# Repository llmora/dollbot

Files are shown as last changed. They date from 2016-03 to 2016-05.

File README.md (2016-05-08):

# dollbot
Water surface autonomous vehicle with holonomic propulsion

More information on http://splashbots.blogspot.com/

Mechanical design
-----------------
The "mechanical" directory includes the CAD design files for the pieces used in dollbot (as well as the STL renderings, ready to 3D print).

The designs are parametric, so you can adjust and play with different measurements - just use OpenSCAD to visualise the results and export to STL. If you plan to work with the SCAD files you will need to install the ["nutsnbolts"](https://github.com/JohK/nutsnbolts)
OpenSCAD library. You can do that easily using git as the dollbot project already include the appropriate references to pull any supporting libraries:
```
$ git submodule init
$ git submodule update
```

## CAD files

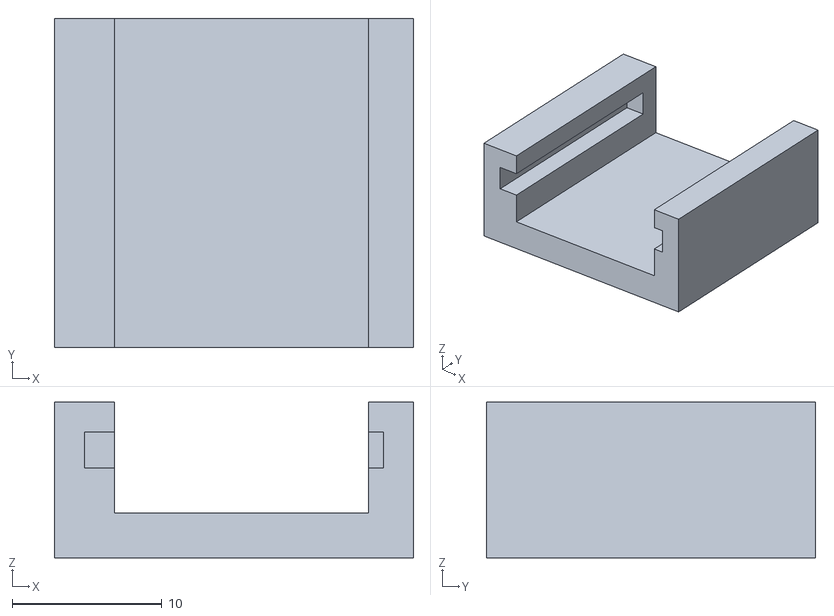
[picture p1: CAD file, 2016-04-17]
mechanical/compass_holder.stl
24.0 x 22.0 x 10.4

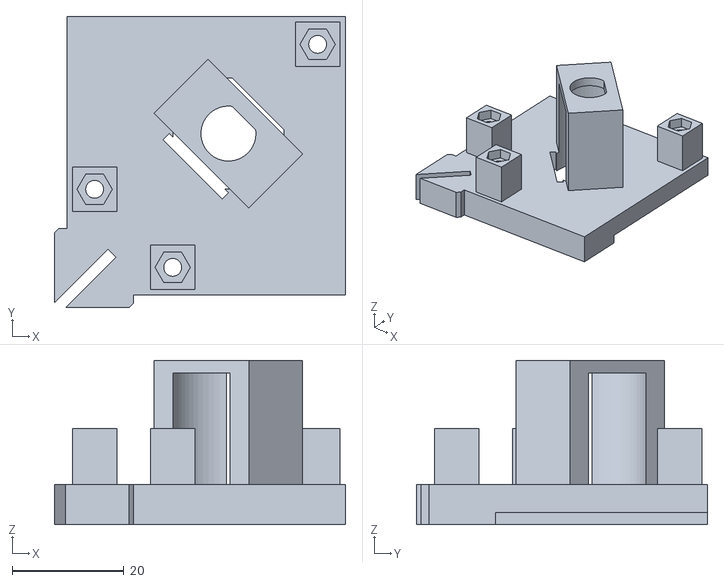
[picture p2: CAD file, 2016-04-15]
mechanical/dollbot_thruster_internal.stl
52.2 x 52.2 x 29.4

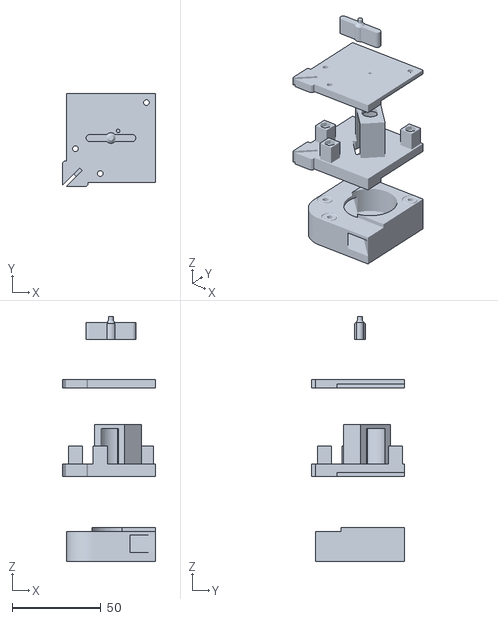
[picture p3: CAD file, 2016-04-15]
mechanical/dollbot_thruster_all.stl
52.2 x 52.2 x 138.0

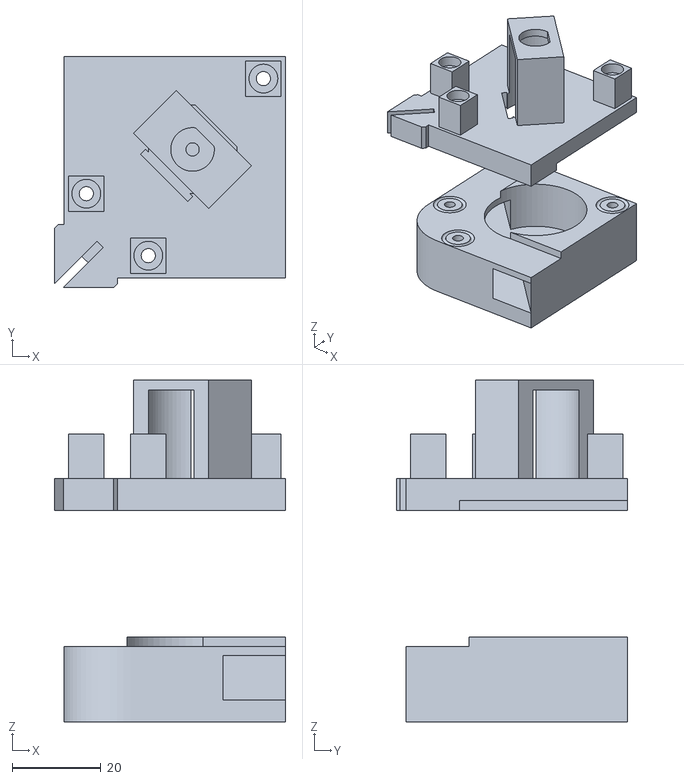
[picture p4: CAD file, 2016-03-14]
mechanical/dollbot_thruster.stl
52.2 x 52.2 x 77.2

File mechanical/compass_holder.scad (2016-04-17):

/*
  HMC5883L Compass holder for Dollbot (http://splashbots.blogspot.com/)

  Small plastic piece to slide-in and hold the 3-axis compass in place in the dollbot hull.
  
  Recommended 20% in-fill with no supports

*/

compass_length = 20;
compass_width = 18;
compass_height= 2.4;
compass_bottom_clearance = 3;
compass_top_clearance = 2;

base_height = 3;

holder_wall_thickness = 2;
holder_length = compass_length + holder_wall_thickness + holder_wall_thickness;
holder_width = compass_width + holder_wall_thickness + holder_wall_thickness;
holder_height = compass_height + base_height + compass_bottom_clearance + compass_top_clearance;

difference() {
  cube([holder_length, holder_width, holder_height]);

  translate([2 * holder_wall_thickness, 0, base_height]) {
    cube([compass_length - 2 - 1, compass_width + holder_wall_thickness + holder_wall_thickness, compass_height + compass_bottom_clearance + compass_top_clearance]);
  }
  
  translate([holder_wall_thickness, 0, base_height + compass_bottom_clearance]) {
      cube([compass_length, compass_width + holder_wall_thickness, compass_height]);
  }
}

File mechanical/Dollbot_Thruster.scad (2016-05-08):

/*
  Holonomic thruster for Dollbot (http://splashbots.blogspot.com/)

  The drawing includes the internal and external components for the thruster as well as the turbines and a stencil to help drill the appropriate holes on the boat hull.

  You should print 4 of each of the components (except for the stencil, of which you need only one). Recommendations are:

  * 4 x External thruster: 20% fill, Supports
  * 4 x Internal thruster: 20% fill, Supports
  * 4 x Turbines: 20% fill, No Supports
  * 1 x Stencil: 20% fill, No Supports

*/

include <nutsnbolts/cyl_head_bolt.scad>;

$fn = 60;

piece_separation = 50;

base_side = 50;
base_height = 5;

pillar_side = 8;
pillar_height = 10; // Should be 30
pillar_base_offset = 1;
pillar_base_offset_side = 3;

pillar_screw_offset = 10;
pillar_screw_name="M3x30";
pillar_screw_details = _get_screw(pillar_screw_name);
pillar_screw_fam = _get_screw_fam(pillar_screw_name);

latch_depth = 2.20;
latch_side = 12 + latch_depth;
latch_fin_length = latch_side;
latch_fin_width = 2;

motor_width = 15.05;
motor_length = 20;
motor_height = 25;

motor_offset = 4;

motor_top_height = 4.5;
motor_top_overhang = 1.55;

motor_holder_radius = 9.85 / 2;
motor_holder_cutoff = 1;
motor_shaft_radius = 1;
motor_shaft_length = 8.4;
motor_shaft_cover_radius = motor_shaft_radius * 3;

thruster_jet_side = 10;
thruster_top_height = 2;
thruster_bottom_height = 5;
thruster_height = thruster_top_height + thruster_jet_side + thruster_bottom_height;
thruster_paddle_radius = 15;
thruster_hull_radius = 15;
thruster_pin_depth = 2;
thruster_pin_radius = 1.5;

rubber_rim_width = 0.6;
drilling_stencil_height = base_height;

thruster_pin_depth = 2;
thruster_pin_radius = 1.5;

turbine_radius = 3;
turbine_height = 13;
turbine_top_radius = thruster_pin_radius * 0.9;
turbine_wings = 2;
turbine_wing_height = turbine_height - 3.50;
turbine_wing_length = 14;
turbine_wing_width = 4;
turbine_bottom_offset = 0;

module pillar(x,y) {
  translate([x-(pillar_side/2), y-(pillar_side/2), base_height]) {
    cube([pillar_side, pillar_side, pillar_height]);
  }
}

module pillar_screw_holes(x, y) {
  ds = _get_screw(pillar_screw_name);
  df = _get_screw_fam(pillar_screw_name);

  union() {
    //translate([x, y, 15.0001 + df[_NB_F_HEAD_HEIGHT]]) {
    translate([x, y, pillar_height + base_height/2 + df[_NB_F_HEAD_HEIGHT] - 0.4999]) {
      nut(df[_NB_F_DESC]);
      hole_through(df[_NB_F_DESC], l=ds[_NB_S_LENGTH] + 100);// h=df[_NB_F_HEAD_HEIGHT]);
      translate([0,0,-piece_separation - thruster_height + df[_NB_F_HEAD_HEIGHT] - 1.1]) {
        rotate(a=180, v=[1,0,0]) {
        hole_through(df[_NB_F_DESC], l=ds[_NB_S_LENGTH] + 100);//, h=df[_NB_F_HEAD_HEIGHT]);
        }
      }
    };
  }
}

// Inside part of the thruster

// Base
module thruster(show_motor_gap) {
  difference() {
    union() {
      translate([0,0,base_height/2]) {
        intersection() {
          union() {
            cube([base_side, base_side, base_height], center=true);

            // Sides

            translate([-base_side/2, -base_side/2, -latch_depth - base_height/2]) {
              cube([latch_side - latch_depth, base_side, latch_depth]);
              translate([0, latch_side-latch_depth, 0]) {
                rotate(a=270, v=[0,0,1]) {
                  cube([latch_side - latch_depth, base_side, latch_depth]);
                }
              }
            }
          }
        }
      };

      // Improve the connection with the bottom of the Dollbot hull

      translate([-base_side/2 - latch_depth, -base_side/2 - latch_depth, -latch_depth]) {

        // Corner

        intersection() {
          translate([latch_side/2,latch_side/2, 0]) {
            cylinder(r=latch_side/2 + (latch_side/6), h = base_height + latch_depth);
          }

          cube([latch_side, latch_side, base_height + latch_depth]);
        };
      }



      // Pillars for screws

      pillar(base_side/2 - pillar_side/2 - pillar_base_offset, base_side/2 - pillar_side/2 - pillar_base_offset);
      pillar(-base_side/2 + pillar_base_offset + pillar_side/2, -pillar_base_offset_side * 2);
      pillar(-pillar_base_offset_side * 2, -base_side/2 + pillar_base_offset + pillar_side/2);

      // DC130 motor holder
      translate([motor_offset, motor_offset, 0]) {
        rotate(a=135, v=[0, 0, 1]) {
          difference() {
            translate([0, 0, (motor_height+base_height)/2]) {
              cube([motor_length*1.2, motor_width/1.10, motor_height + motor_top_height - base_height], center=true);
            };

          // Top of the motor holder indentation to keep motor from moving around

            translate([0,0,motor_height-motor_top_height/2]) {
              difference() {
                cylinder(r=motor_holder_radius, h=motor_top_height);

                translate([-motor_holder_radius, -motor_holder_radius, 0]) {
                  cube([motor_holder_radius*2, motor_holder_cutoff, motor_top_height]);
                }
              };
            }
          };
        }
      }

      translate([base_side/2,-base_side/2,-piece_separation]) {
        rotate(a=90, v=[0,0,1]) {
          // external_thruster();
        }
      }
  }

    // Screw holes

    pillar_screw_holes(base_side/2 - pillar_side/2 - pillar_base_offset, base_side/2 - pillar_side/2 - pillar_base_offset);
    pillar_screw_holes(-base_side/2 + pillar_base_offset + pillar_side/2, -pillar_base_offset_side * 2);
    pillar_screw_holes(-pillar_base_offset_side * 2, -base_side/2 + pillar_base_offset + pillar_side/2);

    translate([-base_side/2 - latch_depth, -base_side/2 - latch_depth, 0]) {
      translate([latch_fin_width/2, -latch_fin_width/2, -latch_depth - 1]) {
        rotate(a=45, v = [0,0,1]) {
          cube([latch_fin_length, latch_fin_width, base_height + latch_depth + 2]);
        }
      }
    }

    // Motor holder block
    if(show_motor_gap) {
      translate([motor_offset, motor_offset, 0]) {

        rotate(a=135, v=[0, 0, 1]) {

          translate([-motor_length/2, -motor_width/2, -latch_depth]) {

            union() {
              intersection() {
                cube([motor_length, motor_width, motor_height+latch_depth]);
                translate([motor_length/2, motor_width/2,0]) {
                  cylinder(r=motor_length/2, h=motor_height+latch_depth);
                }
              };

              translate([(motor_length - motor_width)/2, motor_width, 0]) {
                cube([motor_width, motor_top_overhang, motor_height+latch_depth]);
              }
            }
          };
        }
      }

    } else {
      // Hole for drilling template instead of the motor holder block
      translate([motor_offset, motor_offset, -base_height/2]) {
        // cylinder(r = motor_shaft_cover_radius, h = 100);
        cylinder(r = motor_shaft_radius, h = 100);
      }

    }

  }

}


// Module: External thruster
module external_thruster() {

  difference() {

    union() {
      cube([base_side, base_side, thruster_height]);

      translate([latch_side,0,thruster_height]) {
        difference() {
          cube([base_side - latch_side, base_side - latch_side, latch_depth]);
          translate([0,base_side - (2*latch_side), 0]) {
            cube([latch_side, latch_side, latch_depth]);
          }
        }
      }
    }

    rubber_rim(pillar_base_offset + pillar_side/2, base_side/2 + pillar_side/2 + pillar_base_offset * 2, thruster_height);
    rubber_rim(base_side/2 - pillar_base_offset * 2 - pillar_side/2 , base_side - pillar_side/2 - pillar_base_offset, thruster_height);
    rubber_rim(base_side - pillar_side/2 - pillar_base_offset, pillar_side/2 + pillar_base_offset, thruster_height + latch_depth);

    translate([thruster_hull_radius-0.0001, base_side - thruster_hull_radius, 0]) {
      rotate(a=90, v=[0,0,1]) {
        difference() {
          cube([thruster_hull_radius, thruster_hull_radius, thruster_height]);
          cylinder(r=thruster_hull_radius, h=thruster_height);
        }
      }
    }

    translate([0,0,thruster_bottom_height]) {
      rotate(a=45, v=[0,0,1]) {
        cube([sqrt(2 * pow(base_side, 2)), thruster_jet_side, thruster_jet_side]);
      }
    }

    translate([base_side/2 + motor_offset, base_side/2 - motor_offset, thruster_bottom_height]) {
      cylinder(r=thruster_paddle_radius, h = thruster_top_height + thruster_jet_side + latch_depth);
      translate([0,0,-thruster_pin_depth]) {
        cylinder(r=thruster_pin_radius, h=thruster_pin_depth);
      }
    }
  }
}

module rubber_rim(x, y, z) {
  df = _get_screw_fam(pillar_screw_name);

  translate([x, y, z]) {
    rotate_extrude(convexity = 10)
    translate([df[_NB_F_OUTER_DIA] + rubber_rim_width * 2, 0, 0])
    circle(r = rubber_rim_width);
  }
}

module drilling_stencil() {
  intersection() {
    thruster(false);
    translate([-base_side, -base_side, -base_height/2]) {
      cube([base_side * 2, base_side * 2, drilling_stencil_height]);
    }
  }
}
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

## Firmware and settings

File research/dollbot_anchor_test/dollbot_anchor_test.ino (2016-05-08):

/*
  dollbot_anchor_test: Anchor dollbot in a specific heading

  Control the dollbot via the remote control interface, once control is released the dollbot will stay anchored in the same orientation using its built-in
  magnetic compass.
  
  http://splashbots.blogspot.com/
  
  Based on Sparkfun's "RC Hobby Controllers and Arduino": https://www.sparkfun.com/tutorials/348
  Requires Adafruit MotorShield v2: http://www.adafruit.com/products/1438
  Requires Adafruit HMC5883 and Adafruit sensor library https://learn.adafruit.com/adafruit-hmc5883l-breakout-triple-axis-magnetometer-compass-sensor/

*/

#include <Wire.h>
#include <Adafruit_MotorShield.h>
#include <Adafruit_Sensor.h>
#include <Adafruit_HMC5883_U.h>

// #define DEBUG // Define if you are debugging the project - note that a huge amount of serial debugging plus a 500ms delay is added to each loop to be able to follow serial output, so debugging heavily interferes with any real-time operation.
// #define DEBUG_DRYDOCK // Define together with DEBUG if you are doing workbench testing with no need to have actual motor movement. Generally you do not want the water-designed motors to be spinning out of water for a long period of time.

#define PIN_CH1 7
#define PIN_CH2 6
#define PIN_CH3 5
#define PIN_CH4 4

#define MOTOR_FL 1
#define MOTOR_FR 2
#define MOTOR_BL 3
#define MOTOR_BR 4

// These two values need to be adjusted depending on your RC receiver. Typical values are 1000-2000, see the Sparkfun article referenced above.
#define PWM_LOW 1000
#define PWM_HIGH 1900

#define RC_THRESHOLD 10 // Minimum value of an RC input to move to manual control
#define MOTOR_THRESHOLD 5 // Minimum value of a motor input to spin, smaller than this is considered noise

#define MOTOR_MAX 255

void vehicleMove(int valX, int valY, int valRotate);
void vehicleStop();
void HolonomicMove(int xComponent, int yComponent, int rotationComponent);
void HolonomicSpin(int mm[4]);
void HolonomicSimplify(int mm[4]);
int rotationalDeviation(int initial, int target);

// Holonomic matrix - connect all motors to the motor shield in the same position. If movement is not as expected change the connections (do not change the table below).

int verticalMove[4] =   {-1, -1, -1, -1};
int horizontalMove[4] = {-1, +1, +1, -1};
int rotationMove[4] =   {-1, +1, -1, +1};

// Control variables
int manualControl;
float anchorHeading = 0;

// Create the motor shield object with the default I2C address
Adafruit_MotorShield AFMS = Adafruit_MotorShield(); 
Adafruit_DCMotor *motor[4] = {AFMS.getMotor(MOTOR_FL), AFMS.getMotor(MOTOR_FR), AFMS.getMotor(MOTOR_BL), AFMS.getMotor(MOTOR_BR)};

// Initialise the compass
Adafruit_HMC5883_Unified compass = Adafruit_HMC5883_Unified(8431);

void setup() {
  // Initialize serial communications
  Serial.begin(9600);
  Serial.println("");
  Serial.print("DOLLBOT v1.0 (");

#ifdef DEBUG_DRYDOCK
  Serial.print("DRYDOCK ");
#endif

#ifdef DEBUG
  Serial.print("DEBUG");
#else
  Serial.print("PRODUCTION");
#endif

  Serial.print(") initialising");

  // Seep for 3 seconds
  for(int i=0; i < 3; i++) {
    delay(1000);
    Serial.print(".");
  }
  
  Serial.println("");

  AFMS.begin();  // create with the default frequency 1.6KHz

  /* Initialise the compass */
  if(!compass.begin()) {
    Serial.println("HMC5883 compass not detected, stopping.");
    while(1);
  }
  
  Serial.println("HMC5883 compass initialised");

  // Initialize the ports where we will read receiver input
  pinMode(PIN_CH1, INPUT);
  pinMode(PIN_CH2, INPUT);
  pinMode(PIN_CH3, INPUT);
  pinMode(PIN_CH4, INPUT);

  // Automated control initialisation
  manualControl = 1; 

  Serial.println("DOLLBOT Initialisation completed");
}

void dumpContent(int mm[4]) {
  Serial.print("MOTOR: Input array: ");
  for(int i=0; i < 4; i++) {
    Serial.print(mm[i]);
    Serial.print(",");
  }
  Serial.print(". ");
}

void HolonomicSpin(int mm[4]) {
  HolonomicSimplify(mm);

#ifdef DEBUG
  Serial.print("MOTOR: Setting speeds: ");
#endif

  for(int i = 0; i < 4; i++) {
    
    // Expand range to motor limits
    mm[i] = map(mm[i], -100, 100, -1 * MOTOR_MAX, MOTOR_MAX);
    
    if(abs(mm[i]) > (MOTOR_THRESHOLD * MOTOR_MAX) / 100) {

#ifndef DEBUG_DRYDOCK
      motor[i]->setSpeed(abs(mm[i]));
      motor[i]->run(mm[i] > 0? FORWARD : BACKWARD);
#endif

#ifdef DEBUG
      Serial.print(mm[i]);
#endif
    } else {

#ifndef DEBUG_DRYDOCK
      motor[i]->setSpeed(0);
      motor[i]->run(RELEASE);
#endif

#ifdef DEBUG
      Serial.print("STP");
#endif
    }

#ifdef DEBUG
    if(i < 3) {
      Serial.print(",");
    } else {
      Serial.println("");
    }
#endif
  }
}

void HolonomicSimplify(int mm[4]) {
  int max = 0;

  for(int i = 0; i < 4; i++) {
    int currentValue = abs(mm[i]);
    
    if(currentValue > max) {
      max = currentValue;
    }
  }
  
  // Scale the values so that we stay within the -100 .. 100 range

  if(max > 100) {
    for(int i = 0; i < 4; i++) {
      mm[i] = map(mm[i], -1 * max, max, -100, 100);
    }
  }

}

void HolonomicMove(int xComponent, int yComponent, int rotationComponent) {
  int mm[4] = {0, 0, 0, 0};
  
  if(xComponent) {
    for(int i = 0; i < 4; i++) {
      mm[i] += horizontalMove[i] * xComponent;
    }
  }

  if(yComponent) {
    for(int i = 0; i < 4; i++) {
      mm[i] += verticalMove[i] * yComponent;
    }
  }
  
  if(rotationComponent) {
    for(int i = 0; i < 4; i++) {
      mm[i] += rotationMove[i] * rotationComponent;
    }
  }
  
  HolonomicSpin(mm);
}


/*
  Helper function to move the vehicle 
 
*/

void vehicleMove(int valX, int valY, int valRotate) {
  HolonomicMove(valX, valY, valRotate);
}

void vehicleStop() {
  vehicleMove(0, 0, 0);
}

// From: http://gmc.yoyogames.com/index.php?showtopic=532420

int rotationalDeviation(int initial, int target) {
  return (((target - initial) % 360) + 360 + 180) % 360 - 180;
}

void loop() {
  sensors_event_t compassEvent;
  float heading;

  // Read three of the channels of the RC receiver, we only use three - but you can add a fourth one if needed

  int channelHorizontal = pulseIn(PIN_CH4, HIGH, 25000); // X axis movement
  int channelVertical = pulseIn(PIN_CH2, HIGH, 25000); // Y axis movement
  int channelRotate = pulseIn(PIN_CH1, HIGH, 25000); // Rotation
    
  int directionHorizontal = map(channelHorizontal, PWM_LOW, PWM_HIGH, -100, 100);
  int directionVertical = map(channelVertical, PWM_LOW, PWM_HIGH, -100, 100);
  int angleRotate = map(channelRotate, PWM_LOW, PWM_HIGH, -100, 100);
  
  // If we are receiving control commands from the RC controller bypass autonomous mode

  if((channelHorizontal || channelVertical || channelRotate) && // If we are receiving no pulses it means we are not connected to RC, so ignore manual control
     (abs(directionHorizontal) > RC_THRESHOLD || abs(directionVertical) > RC_THRESHOLD || abs(angleRotate) > RC_THRESHOLD)) { // RC signals are not perfect, we allow for a 10% threshold before switching to it
    
    manualControl = 1;
    
    // Map all readings to a -100 .. +100 range so it is easy to deal with

#ifdef DEBUG    
    Serial.print("MANUAL: RC control ");

    Serial.print("H: ");
    Serial.print(directionHorizontal);

    Serial.print(" V: ");
    Serial.print(directionVertical);

    Serial.print(" R: ");
    Serial.println(angleRotate);
#endif

    vehicleMove(directionHorizontal, directionVertical, angleRotate);
    
  } else {
    // Autonomous control
    compass.getEvent(&compassEvent);
    heading = int(atan2(compassEvent.magnetic.y, compassEvent.magnetic.x) * 180/M_PI + 360) % 360; // Convert radians to degrees
    
    if(manualControl == 1) {
      manualControl = 0;
      // We just came here from being controlled by the RC. Stop all engines and get our anchor heading

      vehicleStop();

      anchorHeading = heading;
#ifdef DEBUG
      Serial.print("AUTONOMOUS: Set new anchor heading: ");
      Serial.println(anchorHeading);
#endif

    } else {
      // Get our current heading and correct it so we remain close to anchor
      int deviation = rotationalDeviation(anchorHeading, heading);

      if(abs(deviation) > 1) {
#ifdef DEBUG
        Serial.print("AUTONOMOUS: Correcting heading by ");
        Serial.println(deviation);
#endif
        vehicleMove(0, 0, deviation);
      } else {
        vehicleStop();

#ifdef DEBUG
        Serial.print("AUTONOMOUS: Not moving, only a small deviation: ");
        Serial.println(deviation);
#endif
      }
      
    }
  }

#ifdef DEBUG  
 delay(1000);
#endif
}

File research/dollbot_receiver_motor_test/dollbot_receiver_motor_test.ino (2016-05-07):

/*
  dollbot_receiver_motor_test: Control a motor using the 4-CH RC receiver.
  
  This sketch polls three of the channels of the RC receiver and spins a motor when one of the channels is working. Designed to test the
  Adafruit motor shield with the RC motor and the motor casing as part of leak testing.
  
  http://splashbots.blogspot.com/
  
  Based on Sparkfun's "RC Hobby Controllers and Arduino": https://www.sparkfun.com/tutorials/348
*/

#include <Wire.h>
#include <Adafruit_MotorShield.h>

#define DEBUG

#define PIN_CH1 7
#define PIN_CH2 6
#define PIN_CH3 5
#define PIN_CH4 4

#define TEST_MOTOR 4

#define PWM_LOW 1000
#define PWM_HIGH 2000
#define RC_THRESHOLD 10

#define AXIS_X 0
#define AXIS_Y 1

#define MOTOR_MAX 255

// Create the motor shield object with the default I2C address
Adafruit_MotorShield AFMS = Adafruit_MotorShield(); 

// Select which 'port' M1, M2, M3 or M4. In this case, M1
Adafruit_DCMotor *testMotor= AFMS.getMotor(TEST_MOTOR);

void setup() {
  // Initialize serial communications
  Serial.begin(9600);
  Serial.println("Initializing input...");
  
  AFMS.begin();  // create with the default frequency 1.6KHz

  // Initialize the ports where we will read receiver input
  pinMode(PIN_CH1, INPUT);
  pinMode(PIN_CH2, INPUT);
  pinMode(PIN_CH3, INPUT);
  pinMode(PIN_CH4, INPUT);

}

void HolonomicMove(int xComponent, int yComponent) {
  if(xComponent) {
    if(xComponent < -10) {
      int sp = (abs(xComponent) * MOTOR_MAX) / 100;
      Serial.print("Setting backward speed to: ");
      Serial.println(sp);
      testMotor->setSpeed(sp); 
      testMotor->run(BACKWARD);
    } else if (xComponent > 10) {
      int sp = (abs(xComponent) * MOTOR_MAX) / 100;
      Serial.print("Setting forward speed to: ");
      Serial.println(sp);
      testMotor->setSpeed(sp); 
      testMotor->run(FORWARD);
    } else {
      Serial.println("Releasing");
      testMotor->run(RELEASE);
    }
  }
}

/*
  Helper function to move the vehicle - or in the current incarnation spin up a motor instead
*/

void vehicleMove(int axis, int val) {
  switch(axis) {
    case AXIS_X:
      HolonomicMove(val, 0);
      break;

    case AXIS_Y:
      HolonomicMove(0, val);
      break;
  }
}

/*
  Helper function to rotate the vehicle - or in the current incarnation spin up a motor instead
*/

void vehicleRotate(int val) {

  /*
  if(val < -10) {
    digitalWrite(LED_TURN_RIGHT, LOW);    
    digitalWrite(LED_TURN_LEFT, HIGH);
    Serial.println("Lighting LEFT");
  } else if (val > 10) {
    digitalWrite(LED_TURN_LEFT, LOW);    
    digitalWrite(LED_TURN_RIGHT, HIGH);
    Serial.println("Lighting RIGHT");
  } else {
    digitalWrite(LED_TURN_LEFT, LOW);    
    digitalWrite(LED_TURN_RIGHT, LOW);
    Serial.println("Lighting OFF");
  }
  */
  
}

void loop() {
  // Read three of the channels of the RC receiver, we only use three - but you can add a fourth one if needed

  int channelHorizontal = pulseIn(PIN_CH4, HIGH, 25000); // X avis movement
  int channelVertical = pulseIn(PIN_CH2, HIGH, 25000); // Y axis movement
  int channelRotate = pulseIn(PIN_CH1, HIGH, 25000); // Rotation
  
  int directionHorizontal = map(channelHorizontal, PWM_LOW, PWM_HIGH, -100, 100);
  int directionVertical = map(channelVertical, PWM_LOW, PWM_HIGH, -100, 100);
  int angleRotate = map(channelRotate, PWM_LOW, PWM_HIGH, -100, 100);
  
  // If we are receiving control commands from the RC controller bypass autonomous mode

  if(abs(directionHorizontal) > RC_THRESHOLD || abs(directionVertical) > RC_THRESHOLD || abs(angleRotate) > RC_THRESHOLD) {
    
    // Map all readings to a -100 .. +100 range so it is easy to deal with


#ifdef DEBUG    
    Serial.print("Manual control ");

    Serial.print("H: ");
    Serial.print(directionHorizontal);

    Serial.print(" V: ");
    Serial.print(directionVertical);

    Serial.print(" R: ");
    Serial.println(angleRotate);
#endif

    vehicleMove(AXIS_X, directionHorizontal);
    vehicleMove(AXIS_Y, directionVertical);
    vehicleRotate(angleRotate);
    
  } else {
    Serial.println("Autonomous control");
    vehicleMove(AXIS_X, 0);
    vehicleMove(AXIS_Y, 0);
    vehicleRotate(0);
  }

#ifdef DEBUG  
 delay(500);
#endif
}

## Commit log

2015-06-06 Added receiver/motor test
2015-06-07 Added RC control of 4 motors
2015-07-18 Added new motor testing recipe
2016-03-07 Added latches to adapt to the Dollbot hull
    [Dollbot_Thruster_V2.scad]
2016-03-07 Corrected the size of the DC130 motor holder
    [Dollbot_Thruster_V2.scad]
2016-03-07 Turned engine block 45 degrees to allow for hull gap
    [Dollbot_Thruster_V2.scad]
2016-03-07 Modified base size to 50mm to match the outer part
    [Dollbot_Thruster_V2.scad]
2016-03-07 Corrected bottom fill width
    [Dollbot_Thruster_V2.scad]
2016-03-08 Reversed orientation of screws Added exterior thruster model
    [Dollbot_Thruster_V2.scad]
2016-03-11 Interior and exterior components finalized
    [Dollbot_Thruster_V2.scad]
2016-03-11 Added drilling stencil
    [Dollbot_Thruster_V2.scad]
2016-03-13 Adjusted turbine hole and height
    [Dollbot_Thruster_V2.scad]
2016-03-14 Modified size of stencil and borders. Successfully tested for water leaks
    [Dollbot_Thruster_V2.scad]
2016-03-14 Completed design, tested as working
    [Dollbot_Thruster_V2.scad]
2016-03-14 Re-structured turbine code
    [Dollbot_Thruster_V2.scad]
2016-03-14 Renamed SCAD file. Added STL files for 3D printing
    [Dollbot_Thruster.scad, dollbot_thruster.stl, dollbot_thruster_all.stl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]
2016-04-15 Modified internal thruster to have nuts to help tighten and avoid water leaks
    [Dollbot_Thruster.scad, dollbot_thruster_all.stl, dollbot_thruster_internal.stl]
2016-04-17 Added compass holder
    [compass_holder.scad, compass_holder.stl]
2016-04-17 Added anchor test file. Corrected size of compass holder
    [compass_holder.scad, compass_holder.stl]
2016-05-07 Fixed holonomic table. Resolved a few issues with anchoring (calculation of degree difference)
    [dollbot_anchor_test.ino, dollbot_receiver_motor_test.ino]
2016-05-08 Added "nutsnbolts" submodule for OpenSCAD rendering of metric nuts and bolts
2016-05-08 Added information on subprojects to README. Removed top protuberance from paddle as it is not used in the current prototype anymore.
    [Dollbot_Thruster.scad]
2016-05-08 Fixed speed mapping code, it was causing values out of range to be set. Added automatic disabling of manual control if RC is not connected
    [dollbot_anchor_test.ino]
